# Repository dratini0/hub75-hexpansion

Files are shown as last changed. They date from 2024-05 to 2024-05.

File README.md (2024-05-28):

# HUB75 hexpansion

As of yet untested

Drives an LED wall panel by a single SPI peripheral.
A single 74HC595 drives the line select lines, this is inserted before the panel.
Then, the serial stream goes through the shift registers in the panel, and it is fed back into the input of the panel from the daisy chain output.
This means that a panel that normally needs a 6-way parallel drive can now be driven with just a single SPI line.
The OE pin is broken out to the high speed IO for a good measure.

The order of the chain is as follows:
1. Shift register
2. R1
3. G1
4. B1
5. R2
6. G2
7. B2

## Acknowledgements

Uses the [hexpansion template from EMF](https://github.com/emfcamp/badge-2024-hardware/tree/main/hexpansion)

I have taken the idea of chaining an LED wall panel with itself from some Youtube video that I have seen years and years ago, and I can no longer locate.

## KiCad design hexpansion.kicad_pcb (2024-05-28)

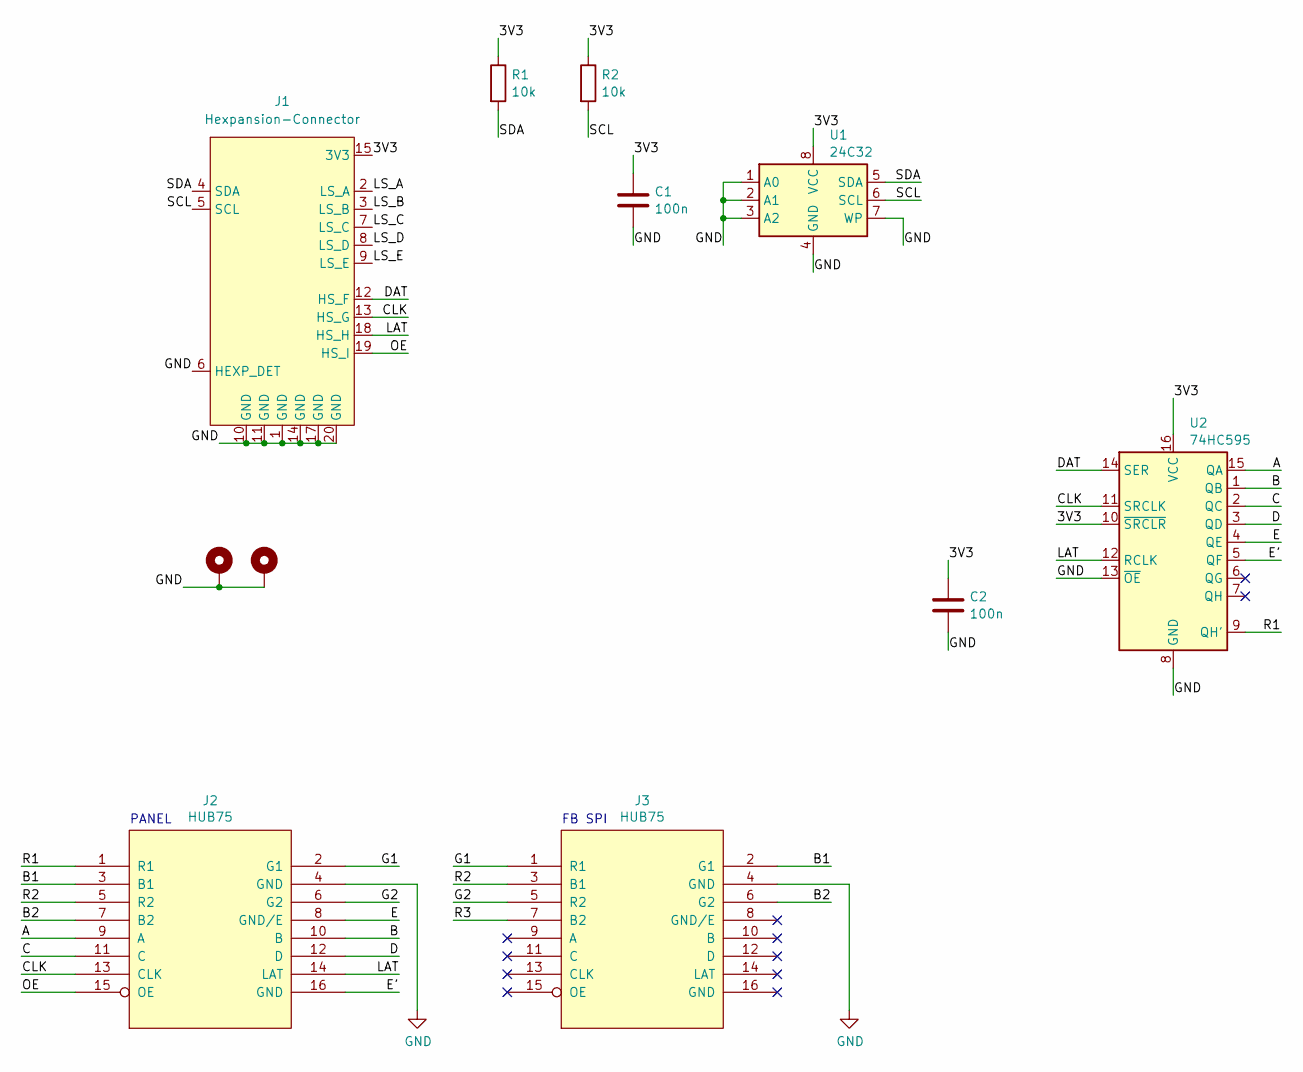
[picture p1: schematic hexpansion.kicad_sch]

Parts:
C1, C2: 100n; C_0805_2012Metric_Pad1.18x1.45mm_HandSolder
H1, H2: MountingHole_Pad; MountingHole_2.2mm_M2_Pad_Via
J1: Hexpansion-Connector; hexpansion-edge-connector
J2, J3: HUB75; IDC-Header_2x08_P2.54mm_Vertical
R1, R2: 10k; R_0805_2012Metric_Pad1.20x1.40mm_HandSolder
U1: 24C32; SOIC-8_3.9x4.9mm_P1.27mm
U2: 74HC595; SOIC-16_3.9x9.9mm_P1.27mm

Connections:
/3V3: C1.1, C2.1, J1.15 (3V3), J1.16 (3V3), R1.1, R2.1, U1.8 (VCC), U2.10 (~SRCLR), U2.16 (VCC)
/A: J2.9 (A), U2.15 (QA)
/B: J2.10 (B), U2.1 (QB)
/B1: J2.3 (B1), J3.2 (G1)
/B2: J2.7 (B2), J3.6 (G2)
/C: J2.11 (C), U2.2 (QC)
/CLK: J1.13 (HS_G), J2.13 (CLK), U2.11 (SRCLK)
/D: J2.12 (D), U2.3 (QD)
/DAT: J1.12 (HS_F), U2.14 (SER)
/E: J2.8 (GND/E), U2.4 (QE)
/E': J2.16 (GND), U2.5 (QF)
/G1: J2.2 (G1), J3.1 (R1)
/G2: J2.6 (G2), J3.5 (R2)
/LAT: J1.18 (HS_H), J2.14 (LAT), U2.12 (RCLK)
/LS_A: J1.2 (LS_A)
/LS_B: J1.3 (LS_B)
/LS_C: J1.7 (LS_C)
/LS_D: J1.8 (LS_D)
/LS_E: J1.9 (LS_E)
/OE: J1.19 (HS_I), J2.15 (OE)
/R1: J2.1 (R1), U2.9 (QH')
/R2: J2.5 (R2), J3.3 (B1)
/R3: J3.7 (B2)
/SCL: J1.5 (SCL), R2.2, U1.6 (SCL)
/SDA: J1.4 (SDA), R1.2, U1.5 (SDA)
GND: C1.2, C2.2, H1.1, H2.1, J1.1 (GND), J1.6 (HEXP_DET), J1.10 (GND), J1.11 (GND), J1.14 (GND), J1.17 (GND), J1.20 (GND), J2.4 (GND), J3.4 (GND), U1.1 (A0), U1.2 (A1), U1.3 (A2), U1.4 (GND), U1.7 (WP), U2.8 (GND), U2.13 (~OE)

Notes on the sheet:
PANEL
FB SPI

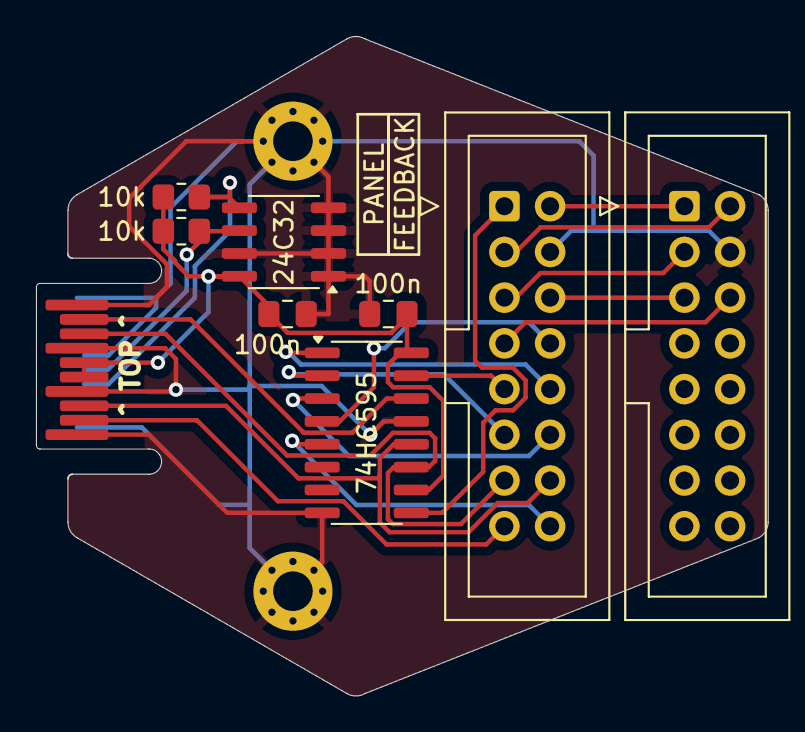
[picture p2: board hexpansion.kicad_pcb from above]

Board: 2 copper layers, 40.7 x 36.6 mm, 11 parts (0 on the bottom side), 20 nets.
